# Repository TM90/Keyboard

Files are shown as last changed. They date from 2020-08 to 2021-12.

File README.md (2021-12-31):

# DIY Mechanical Keyboard

## Main Idea:

Have as much as possible open source? Also the tools used to build the keyboard

## Tool usage:
1. KiCAD (schematic, layout) (http://kicad.org/ )
2. avr-gcc (https://gcc.gnu.org/wiki/avr-gcc )
3. Export data for alu body from a layer in the KiCAD layout data

## Electronic
Own layout and schematic but based on this project to keep compatibility with tmk firmware and qmk firmware:

<https://github.com/tmk/HHKB_controller/blob/master/schematic/HHKB_controller_revG.pdf>

### Datasheets

#### Power
- LM1117 3.3V LDO http://cdn-reichelt.de/documents/datenblatt/A200/LM1117-TI.pdf
- NCP1402 step up DCDC Converter https://www.onsemi.com/pub/Collateral/NCP1402-D.PDF ->farnell: out of production
      - Alternative MAX1724 https://www.mouser.de/datasheet/2/256/MAX1722-MAX1724-97057.pdf but no Kicad Lib yet
- MCP 73831/2 Single Cell Lipo Charge Management Controller http://ww1.microchip.com/downloads/en/DeviceDoc/20001984g.pdf

#### Bluetooth
- RN42 Bluetooth Module http://ww1.microchip.com/downloads/en/DeviceDoc/50002328A.pdf

#### Microcontroller
- ATMEGA32U4 8 bit Microcontroller with USB http://ww1.microchip.com/downloads/en/devicedoc/atmel-7766-8-bit-avr-atmega16u4-32u4_datasheet.pdf
- AT90USB1286 8 bit Microcontroller with USB but more IO than ATMEGA32U4  http://ww1.microchip.com/downloads/en/DeviceDoc/doc7593.pdf

## Mechanical
<http://builder.swillkb.com/>

Sandwich case or alu bend case

## Software/Firmware
- <https://qmk.fm/>
- <https://github.com/tmk/tmk_keyboard>

## Other:
<http://www.keyboard-layout-editor.com/#/>

Prototype for Switches without big PCB and description how to build a small keyboard:
<https://learn.sparkfun.com/tutorials/cherry-mx-switch-breakout-hookup-guide>

Fullsize Keyboard matrix example with atmega32u4:
<https://easyeda.com/farmakon/GH80_3000-4f3cee521afd4be3858c4b5cc3b76f9e>

## Manufacturer:
### PCB:
- beta layout <https://de.beta-layout.com/leiterplatten/> 
- LiteOn <https://www.leiton.de/index.html> 
- jlcpcb <https://jlcpcb.com/>
### Mechanical:
Maybe using a front panel service for the keyboard front, aluminum or acrylic would be possible at beta layout

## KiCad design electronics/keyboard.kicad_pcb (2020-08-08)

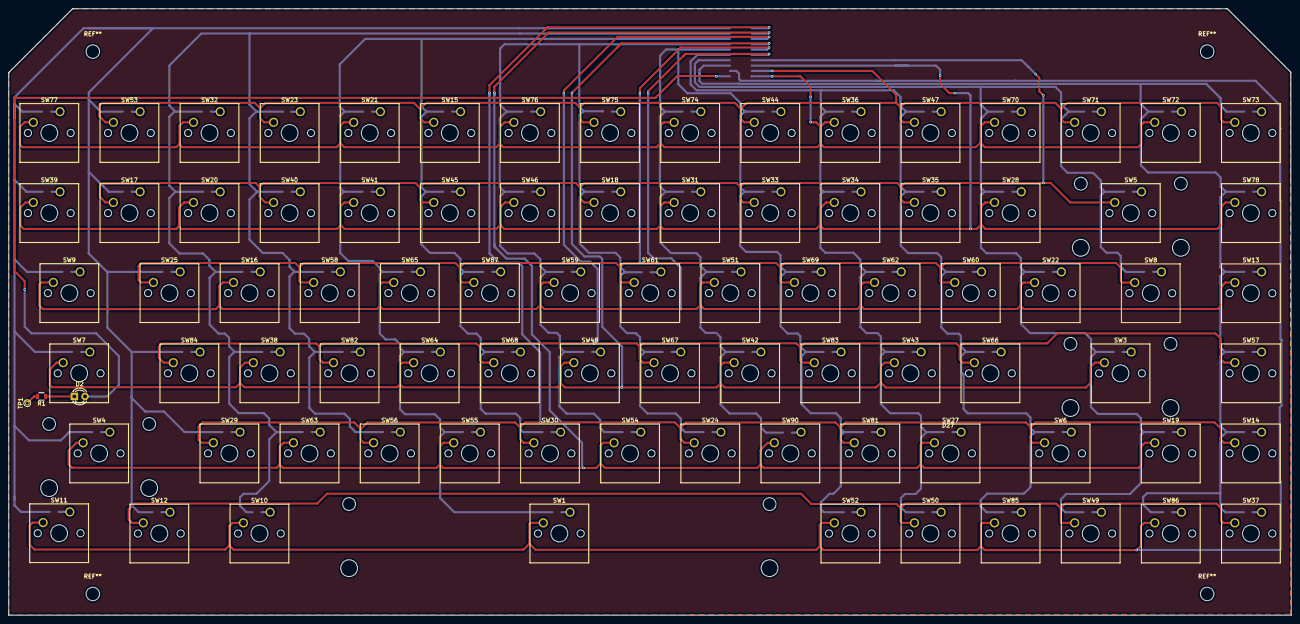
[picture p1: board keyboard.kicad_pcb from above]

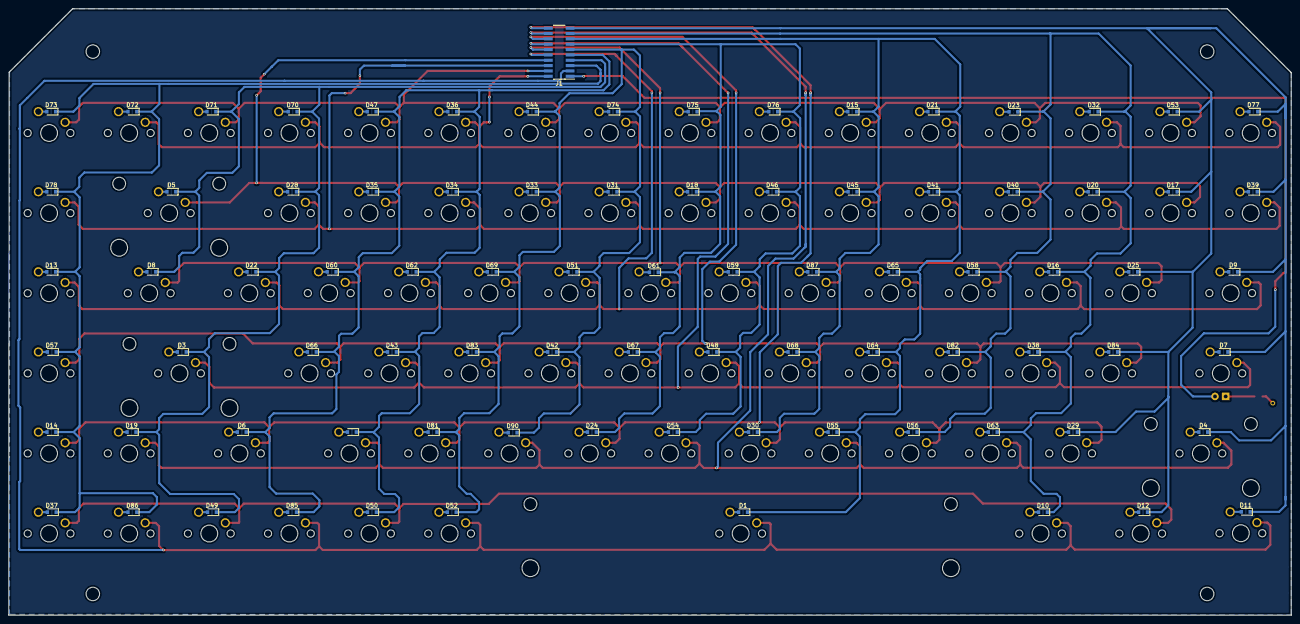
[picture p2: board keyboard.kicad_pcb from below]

Board: 2 copper layers, 305.0 x 144.2 mm, 172 parts (85 on the bottom side), 107 nets.

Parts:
D1, D3, D4, D5, D6, D7, D8, D9, D10, D11, D12, D13, D14, D15, D16, D17, D18, D19, D20, D21, D22, D23, D24, D25, D27, D28, D29, D30, D31, D32, D33, D34, D35, D36, D37, D38, D39, D40, D41, D42, D43, D44, D45, D46, D47, D48, D49, D50, D51, D52, D53, D54, D55, D56, D57, D58, D59, D60, D61, D62, D63, D64, D65, D66, D67, D68, D69, D70, D71, D72, D73, D74, D75, D76, D77, D78, D81, D82, D83, D84, D85, D86, D87, D90: D; D_0805
D2: LED; LED_D3.0mm
J1: CONN_02X10; Pin_Header_Straight_2x10_Pitch1.27mm_SMD
R1: 10k; R_0805
SW1: SW_Push; SW_Cherry_MX1A_6.25u_PCB
SW3, SW4: SW_Push; SW_Cherry_MX1A_2.25u_PCB
SW5: SW_Push; SW_Cherry_MX1A_2.00u_PCB
SW6, SW7: SW_Push; SW_Cherry_MX1A_1.75u_PCB
SW8, SW9: SW_Push; SW_Cherry_MX1A_1.50u_PCB
SW10, SW11, SW12: SW_Push; SW_Cherry_MX1A_1.25u_PCB
SW13, SW14, SW15, SW16, SW17, SW18, SW19, SW20, SW21, SW22, SW23, SW24, SW25, SW27, SW28, SW29, SW30, SW31, SW32, SW33, SW34, SW35, SW36, SW37, SW38, SW39, SW40, SW41, SW42, SW43, SW44, SW45, SW46, SW47, SW48, SW49, SW50, SW51, SW52, SW53, SW54, SW55, SW56, SW57, SW58, SW59, SW60, SW61, SW62, SW63, SW64, SW65, SW66, SW67, SW68, SW69, SW70, SW71, SW72, SW73, SW74, SW75, SW76, SW77, SW78, SW81, SW82, SW83, SW84, SW85, SW86, SW87, SW90: SW_Push; SW_Cherry_MX1A_1.00u_PCB
TP1: TestPoint; PINTST

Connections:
/PA0: D4.1, D7.1, D9.1, D11.1, D12.1, D17.1, D25.1, D29.1, D39.1, D53.1, D77.1, D84.1, J1.19
/PA1: D10.1, D16.1, D20.1, D23.1, D32.1, D38.1, D40.1, D56.1, D58.1, D63.1, D82.1, J1.17
/PA2: D1.1, D15.1, D21.1, D30.1, D41.1, D45.1, D55.1, D64.1, D65.1, D68.1, D87.1, J1.15
/PA3: D18.1, D24.1, D46.1, D48.1, D54.1, D59.1, D61.1, D67.1, D75.1, D76.1, J1.13
/PA4: D31.1, D33.1, D42.1, D44.1, D51.1, D52.1, D69.1, D74.1, D81.1, D83.1, D90.1, J1.11
/PA5: D6.1, D27.1, D34.1, D35.1, D36.1, D43.1, D47.1, D50.1, D60.1, D62.1, D66.1, D85.1, J1.9
/PA6: D3.1, D5.1, D8.1, D19.1, D22.1, D28.1, D49.1, D70.1, D71.1, J1.7
/PA7: D13.1, D14.1, D37.1, D57.1, D72.1, D73.1, D78.1, D86.1, J1.5
/PB0: J1.2, SW21.2, SW32.2, SW36.2, SW70.2, SW72.2, SW74.2, SW76.2, SW77.2
/PB1: J1.4, SW15.2, SW23.2, SW44.2, SW47.2, SW53.2, SW71.2, SW73.2, SW75.2
/PB2: J1.6, SW20.2, SW28.2, SW31.2, SW34.2, SW39.2, SW41.2, SW46.2, SW78.2
/PB3: J1.8, SW5.2, SW17.2, SW18.2, SW33.2, SW35.2, SW40.2, SW45.2
/PB4: J1.10, SW9.2, SW13.2, SW16.2, SW22.2, SW51.2, SW59.2, SW62.2, SW65.2
/PB5: J1.12, SW8.2, SW25.2, SW58.2, SW60.2, SW61.2, SW69.2, SW87.2
/PB6: J1.14, SW3.2, SW7.2, SW38.2, SW42.2, SW43.2, SW48.2, SW64.2
/PB7: J1.16, SW57.2, SW66.2, SW67.2, SW68.2, SW82.2, SW83.2, SW84.2
/PC0: J1.18, SW4.2, SW19.2, SW27.2, SW54.2, SW55.2, SW63.2, SW90.2
/PC1: J1.20, SW6.2, SW14.2, SW24.2, SW29.2, SW30.2, SW56.2, SW81.2
/PC2: J1.3, SW1.2, SW10.2, SW11.2, SW52.2, SW85.2, SW86.2
/SwitchMatrix/COL11: SW12.2, SW37.2, SW49.2, SW50.2
unnamed: D1.2, SW1.1
unnamed: D2.1, R1.1
unnamed: D2.2, J1.1
unnamed: D3.2, SW3.1
unnamed: D4.2, SW4.1
unnamed: D5.2, SW5.1
unnamed: D6.2, SW6.1
unnamed: D7.2, SW7.1
unnamed: D8.2, SW8.1
unnamed: D9.2, SW9.1
unnamed: D10.2, SW10.1
unnamed: D11.2, SW11.1
unnamed: D12.2, SW12.1
unnamed: D13.2, SW13.1
unnamed: D14.2, SW14.1
unnamed: D15.2, SW15.1
unnamed: D16.2, SW16.1
unnamed: D17.2, SW17.1
unnamed: D18.2, SW18.1
unnamed: D19.2, SW19.1
unnamed: D20.2, SW20.1
unnamed: D21.2, SW21.1
unnamed: D22.2, SW22.1
unnamed: D23.2, SW23.1
unnamed: D24.2, SW24.1
unnamed: D25.2, SW25.1
unnamed: D27.2, SW27.1
unnamed: D28.2, SW28.1
unnamed: D29.2, SW29.1
unnamed: D30.2, SW30.1
unnamed: D31.2, SW31.1
unnamed: D32.2, SW32.1
unnamed: D33.2, SW33.1
unnamed: D34.2, SW34.1
unnamed: D35.2, SW35.1
unnamed: D36.2, SW36.1
unnamed: D37.2, SW37.1
unnamed: D38.2, SW38.1
unnamed: D39.2, SW39.1
unnamed: D40.2, SW40.1
unnamed: D41.2, SW41.1
unnamed: D42.2, SW42.1
unnamed: D43.2, SW43.1
unnamed: D44.2, SW44.1
unnamed: D45.2, SW45.1
unnamed: D46.2, SW46.1
unnamed: D47.2, SW47.1
unnamed: D48.2, SW48.1
unnamed: D49.2, SW49.1
unnamed: D50.2, SW50.1
unnamed: D51.2, SW51.1
unnamed: D52.2, SW52.1
unnamed: D53.2, SW53.1
unnamed: D54.2, SW54.1
unnamed: D55.2, SW55.1
unnamed: D56.2, SW56.1
unnamed: D57.2, SW57.1
unnamed: D58.2, SW58.1
unnamed: D59.2, SW59.1
unnamed: D60.2, SW60.1
unnamed: D61.2, SW61.1
unnamed: D62.2, SW62.1
unnamed: D63.2, SW63.1
unnamed: D64.2, SW64.1
unnamed: D65.2, SW65.1
unnamed: D66.2, SW66.1
unnamed: D67.2, SW67.1
unnamed: D68.2, SW68.1
unnamed: D69.2, SW69.1
unnamed: D70.2, SW70.1
unnamed: D71.2, SW71.1
unnamed: D72.2, SW72.1
unnamed: D73.2, SW73.1
unnamed: D74.2, SW74.1
unnamed: D75.2, SW75.1
unnamed: D76.2, SW76.1
unnamed: D77.2, SW77.1
unnamed: D78.2, SW78.1
unnamed: D81.2, SW81.1
unnamed: D82.2, SW82.1
unnamed: D83.2, SW83.1
unnamed: D84.2, SW84.1
unnamed: D85.2, SW85.1
unnamed: D86.2, SW86.1
unnamed: D87.2, SW87.1
unnamed: D90.2, SW90.1
unnamed: R1.2, TP1.1

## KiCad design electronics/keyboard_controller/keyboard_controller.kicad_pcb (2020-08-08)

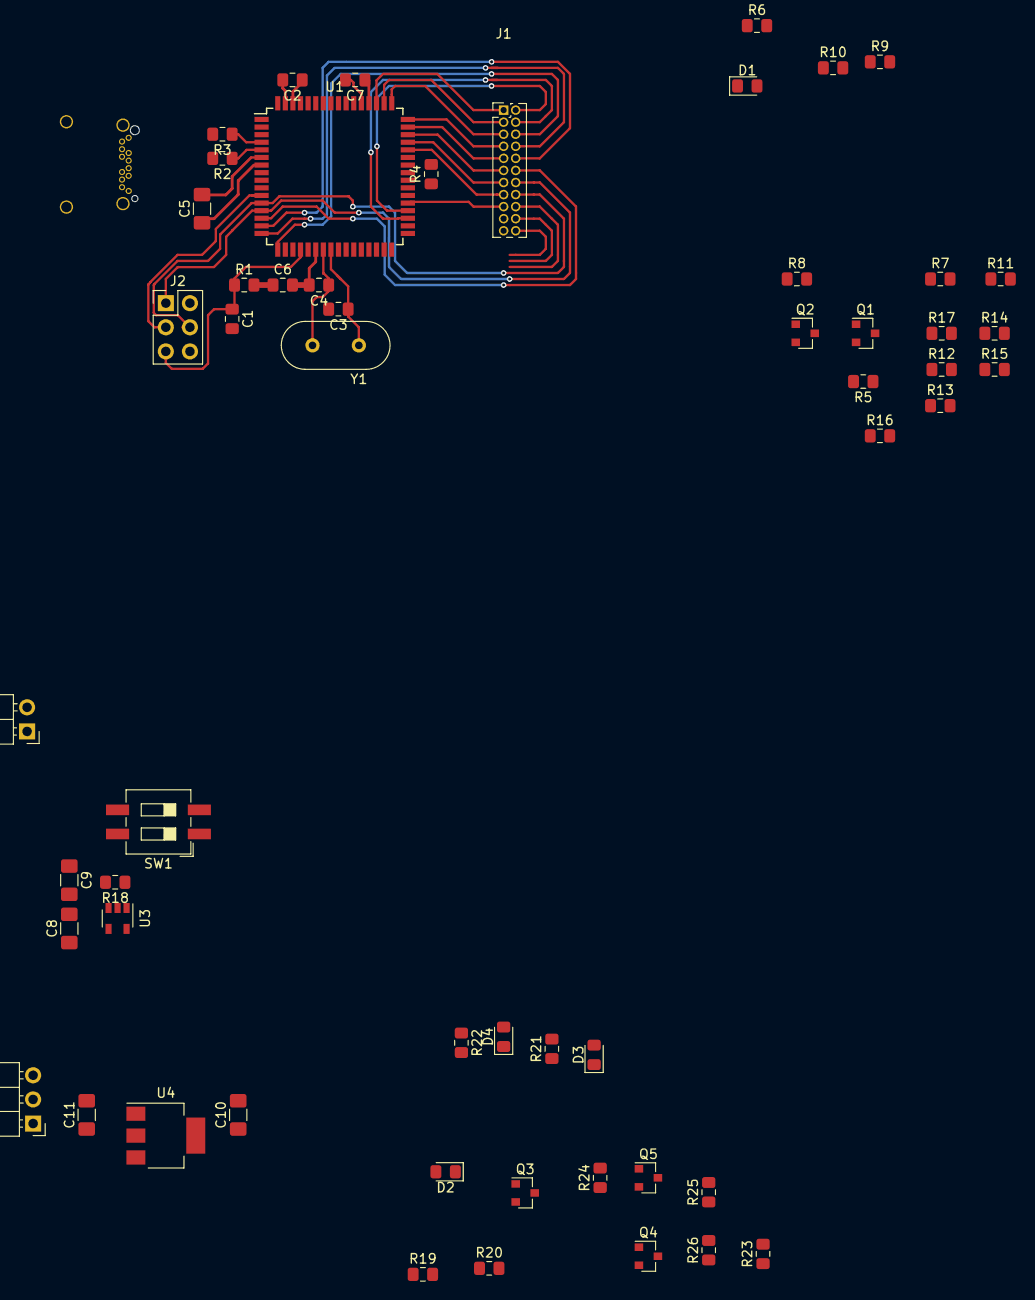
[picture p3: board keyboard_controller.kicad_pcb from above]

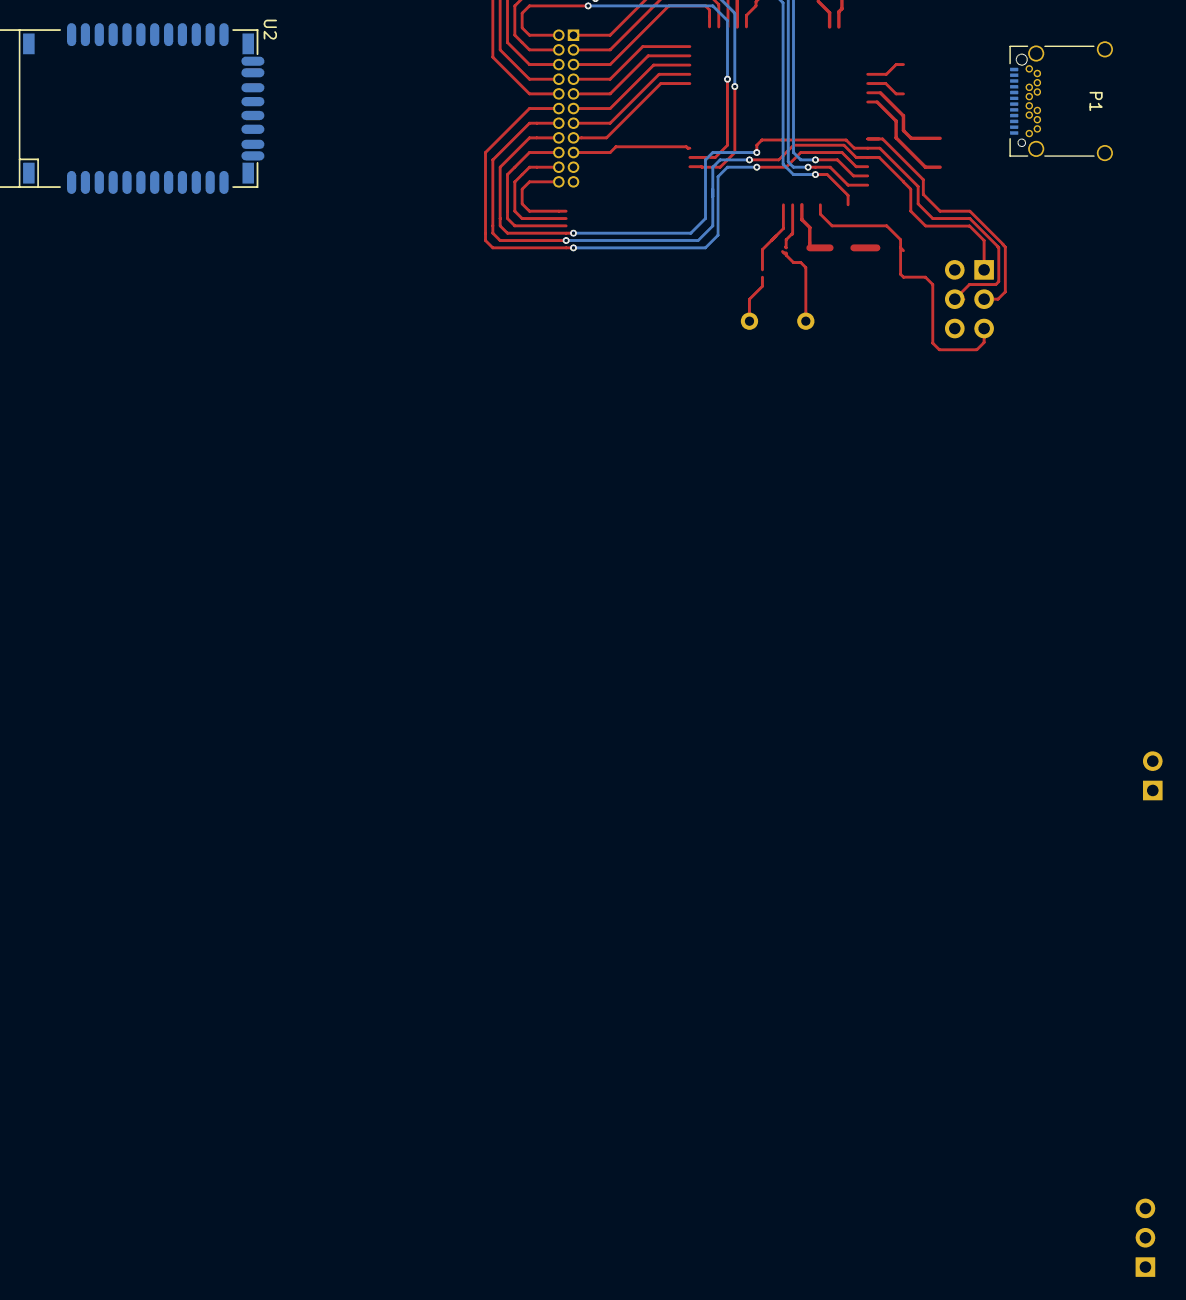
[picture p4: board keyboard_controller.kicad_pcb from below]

Board: 2 copper layers, 57 parts (2 on the bottom side), 62 nets.

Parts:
C1, C2, C6, C7: 100n; C_0805_2012Metric_Pad1.15x1.40mm_HandSolder
C3, C4: 22p; C_0805_2012Metric_Pad1.15x1.40mm_HandSolder
C5: 1u; C_1206_3216Metric_Pad1.42x1.75mm_HandSolder
C8, C9: 4u7; C_1206_3216Metric_Pad1.42x1.75mm_HandSolder
C10, C11: 10u; C_1206_3216Metric_Pad1.42x1.75mm_HandSolder
D1, D3, D4: LED; LED_0805_2012Metric_Pad1.15x1.40mm_HandSolder
D2: D_Schottky; D_0805_2012Metric_Pad1.15x1.40mm_HandSolder
J1: Conn_02x11_Odd_Even; PinHeader_2x11_P1.27mm_Vertical
J2: AVR-ISP-6; PinHeader_2x03_P2.54mm_Vertical
J3: Conn_01x02_Male; PinHeader_1x02_P2.54mm_Horizontal
J4: Conn_01x03_Male; PinHeader_1x03_P2.54mm_Horizontal
P1: USB_C_Plug_USB2.0; USB_C_Receptacle_Amphenol_12401548E4-2A_CircularHoles
Q1, Q2, Q4: Q_NMOS_DGS; SOT-23
Q3, Q5: Q_PMOS_DGS; SOT-23
R1, R4, R6, R19, R21, R22: 1k; R_0805_2012Metric_Pad1.15x1.40mm_HandSolder
R2, R3: 22; R_0805_2012Metric_Pad1.15x1.40mm_HandSolder
R5, R7, R8, R10, R11, R12, R14, R16, R20, R23, R24, R25, R26: 10k; R_0805_2012Metric_Pad1.15x1.40mm_HandSolder
R9: 0; R_0805_2012Metric_Pad1.15x1.40mm_HandSolder
R13, R15, R17: 15k; R_0805_2012Metric_Pad1.15x1.40mm_HandSolder
R18: PROG; R_0805_2012Metric_Pad1.15x1.40mm_HandSolder
SW1: SW_DPST; SW_DIP_SPSTx02_Slide_6.7x6.64mm_W8.61mm_P2.54mm_LowProfile
U1: AT90USB1286-AU; TQFP-64_14x14mm_P0.8mm
U2: RN42
U3: MCP73832-3-OT; SOT-23-5
U4: LM1117-3.3; SOT-223-3_TabPin2
Y1: 16MHz; Crystal_HC49-4H_Vertical

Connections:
+3V3: Q1.2, Q2.2, R5.2, R6.2, R8.2, R10.1, SW1.2, U2.11
+5V: C6.1, C7.1, C10.1, J2.2, J4.1, R1.2, R7.1, R11.1, U1.21, U1.52, U1.64, U4.3
/AREF: C2.1, U1.62
/CONN: R12.1, R13.2, U2.3
/DMINUS: P1.A7, R3.2
/DPLUS: P1.A6, R2.2
/FACTORY_RESET: R9.2, U2.22
/LED_STS: D1.1, U2.21
/LINKED: U1.55, U2.19
/MCU_RX: Q1.1, R7.2, U1.27
/MCU_TX: R14.2, U1.28
/PA0: J1.1, U1.51
/PA1: J1.3, U1.50
/PA2: J1.5, U1.49
/PA3: J1.7, U1.48
/PA4: J1.9, U1.47
/PA5: J1.11, U1.46
/PA6: J1.13, U1.45
/PA7: J1.15, U1.44
/PB0: J1.20, U1.10
/PB1: J1.18, J2.3, U1.11
/PB2: J1.16, J2.4, U1.12
/PB3: J1.14, J2.1, U1.13
/PB4: J1.12, U1.14
/PB5: J1.10, U1.15
/PB6: J1.8, U1.16
/PB7: J1.6, U1.17
/PC0: J1.4, U1.35
/PC1: J1.2, U1.36
/PC2: J1.17, U1.37
/PC3: J1.22, U1.38
/PD5: R16.2, U1.30
/PF0: R25.1, R26.2, U1.61
/PF1: Q2.1, R11.2, U1.60
/PF4: Q4.2, R23.2, U1.57
/PF7: R12.2, U1.54
/RESET: C1.1, J2.5, R1.1, U1.20
/RN42_CTS: R16.1, R17.2, U2.16
/RN42_RTS: Q2.3, R8.1, U2.15
/RN42_RX: R14.1, R15.2, U2.13
/RN42_TX: Q1.3, R5.1, U2.14
/Sheet5D061573/Chrg: D4.1, U3.1
/Sheet5D061573/LIPO_RAW: C9.1, J3.1, Q5.1, R24.2, SW1.3, U3.3
/Sheet5D061573/LIPO_SW: Q3.3, SW1.4
/Sheet5D061573/PSEL: D2.1, J4.3, Q3.1, R22.2
/Sheet5D061573/Vout33_int: C11.1, SW1.1, U4.2
/VUSB: C8.1, D2.2, P1.A4, P1.A9, P1.B4, P1.B9, R19.2, R21.2, U1.3, U1.8, U3.4
GND: C1.2, C2.2, C3.2, C4.2, C5.2, C6.2, C7.2, C8.2, C9.2, C10.2, C11.2, D3.1, J1.21, J2.6, J3.2, J4.2, P1.A1, P1.A12, P1.B1, P1.B12, P1.S1, Q4.3, R4.1, R13.1, R15.1, R17.1, R18.2, R20.1, R23.1, R26.1, U1.6, U1.22, U1.53, U1.63, U2.1, U2.12, U2.28, U2.29, U2.36, U3.2, U4.1
unnamed: C3.1, U1.24, Y1.1
unnamed: C4.1, U1.23, Y1.2
unnamed: C5.1, U1.7
unnamed: D1.2, R6.1
unnamed: D3.2, R21.1
unnamed: D4.2, R22.1
unnamed: Q3.2, R19.1, R20.2
unnamed: Q4.1, Q5.2, R24.1
unnamed: Q5.3, R25.2
unnamed: R2.1, U1.5
unnamed: R3.1, U1.4
unnamed: R4.2, U1.43
unnamed: R9.1, R10.2
unnamed: R18.1, U3.5

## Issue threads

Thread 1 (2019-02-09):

Add GND pin to pinheader for next version

TM90, 2019-02-09:
At the current version in the test pcb the GND Pin for the shif key LED is added as test pin and not on the pin header.

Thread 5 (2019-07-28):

COL11 not connected

TM90, 2019-07-28:
Extend the connector in the keyboard schematic...
Workaround at the moment Connect COL11 with a connector from SW12 to the led which leads to the connector

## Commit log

2018-07-02 Added link for Cherry MX switch breakout board.
2018-07-06 Added initial Schematic
    - Todo
    - Add Bluetooth Module
    - Add Lipo Power Supply
    - connect switch matrix
    [SwitchMatrix.sch, keyboard.kicad_pcb, keyboard.sch]
2018-07-06 Updated .gitignore to ignore kicad backups and other temp files
2018-07-06 Added some structure to the schematics`
    [Interfaces.sch, Supply.sch, SwitchMatrix.sch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]
2018-07-07 Updated Structure
    - ISP programmer is now on interface sheet
    - added en and decoder to SwitchMatrix sheet
    [Interfaces.sch, SwitchMatrix.sch, keyboard.sch]
2018-07-07 Added Reset circuit and decap for en and decoders
    [Supply.sch, SwitchMatrix.sch, keyboard.sch]
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2018-07-21 Added additional Supply for remote usage.
    Started working on Bluetooth `
    [Interfaces.sch, Supply.sch, SwitchMatrix.sch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]
2018-07-21 Added Bluetoothmodule
    Now only the switch matrix is missing
    [Interfaces.sch, keyboard.sch]
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2018-08-10 Changed Controller to AT90USB now the additional circuitry at the matrix can be removed
    [Interfaces.sch, Supply.sch, SwitchMatrix.sch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]
2018-08-10 removed en and decoder from matrix now the controls are direct
    [SwitchMatrix.sch, keyboard.sch]
2018-08-10 Finished the matrix
    Now the schematic should be at an initial finished point
    [SwitchMatrix.sch, keyboard.sch]
2018-08-11 Annotated the schematics...
    Did a first ERC run looked fine...
    [Interfaces.sch, Supply.sch, SwitchMatrix.sch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]
2018-08-11 create an initial netlist and started assigning the footprints
    [Interfaces.sch, Supply.sch, SwitchMatrix.sch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]
2018-08-25 Started placement step
    [keyboard.kicad_pcb]
2018-08-25 Seperated the Buttons from the rest
    [keyboard.kicad_pcb]
2018-08-25 Seperated diodes
    [keyboard.kicad_pcb]
2018-08-25 seperated elements for the controller
    [keyboard.kicad_pcb]
2018-08-25 Clustured Suplly Circuitry
    [keyboard.kicad_pcb]
2018-08-27 Seperated elements in a sane way...
    [Interfaces.sch, Supply.sch, SwitchMatrix.sch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]
2018-08-29 Updated the usb connector to micro usb at the momement because it is in the lib
    [Interfaces.sch, keyboard.kicad_pcb]
2018-08-29 Started working on the switches placements
    [keyboard.kicad_pcb]
2018-09-16 Worked on Placement changed the mothod to do it...
    [keyboard.kicad_pcb]
2018-09-16 Placement progress now only 1u elements left for placment of the switch matrix
    [keyboard.kicad_pcb]
2018-09-16 Initial Placement for the switches
    [keyboard.kicad_pcb]
2018-09-22 Placed Diodes and Main controller
    [keyboard.kicad_pcb]
2018-09-22 Added dimension as indecator
    [keyboard.kicad_pcb]
2018-10-10 Changed keyboard schematic since now keyboard and controller will be seperated
    [Interfaces.sch, Supply.sch, SwitchMatrix.sch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]
2018-10-12 Placed everthing again :(
    [keyboard.kicad_pcb]
2018-10-12 Started routing for this the schematic also gets restructured
    [keyboard.kicad_pcb]
2018-10-12 routed another row
    [SwitchMatrix.sch, keyboard.kicad_pcb]
2018-10-12 routed the 2nd column
    [SwitchMatrix.sch, keyboard.kicad_pcb]
2018-10-13 Added two columns
    [SwitchMatrix.sch, keyboard.kicad_pcb]
2018-10-13 Worked further on the layout
    [SwitchMatrix.sch, keyboard.kicad_pcb]
2018-10-13 more layout
    [SwitchMatrix.sch, keyboard.kicad_pcb]
2018-10-21 worked further on interconnect
    [SwitchMatrix.sch, keyboard.kicad_pcb]
2018-10-21 Further work on interconnect
    [SwitchMatrix.sch, keyboard.kicad_pcb]
2018-10-21 Another ROW layouted
    [SwitchMatrix.sch, keyboard.kicad_pcb]
2018-10-21 Finished Row layout
    Todo:
    - Route the last columns
    - change some layers in the layout (diodes, connector)
    - add fill
    [SwitchMatrix.sch, keyboard.kicad_pcb]
2018-10-22 routed two columns
    [SwitchMatrix.sch, keyboard.kicad_pcb]
2018-10-22 Added another column 3 left
    [SwitchMatrix.sch, keyboard.kicad_pcb]
2018-10-24 Added another column 2 to go
    [SwitchMatrix.sch, keyboard.kicad_pcb]
2018-10-25 Signal Routing done!
    - Area Fill
    - change the layers of rows and columns to swap the diodes away from
    the top
    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
    [SwitchMatrix.sch, keyboard.kicad_pcb]
2018-10-30 Device Cleanup:
    - Fill areas
    - change layers of diodes
    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
    [SwitchMatrix.sch, keyboard.kicad_pcb]
2018-10-30 Changed layers for the routes now diodes have to be moved to the other side
    [keyboard.kicad_pcb]
2018-10-30 Updated connector placed the diodes on the right side.
    - Area fill
    - some routing to the connector
    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
    [keyboard.kicad_pcb, keyboard.sch]
2018-10-31 Corrected some footprints worked on connector routing 4 pins to go...
    [keyboard.kicad_pcb]
2018-10-31 Initial complete signal routing of the connector
    [keyboard.kicad_pcb]
2019-01-05 Fixed strange drc errors with replacing vias
    [keyboard.kicad_pcb]
2019-01-06 Added outline and some drill holes
    todo:
    - Additional 2 drill holes
    - update fill zones
    - add led for shift switch
    [keyboard.kicad_pcb]
2019-01-06 updated pcb
    [keyboard.kicad_pcb]
2019-01-06 Update keyboard.kicad_pcb
    Updated Via size
    Fixed fill area size
    - 2 additional drill holes
    - led for shift
    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
    [keyboard.kicad_pcb]
2019-01-07 kicad5 fix and shift led in schematic
    - Fixed schematic for kicad5
    - added shift led in schematic
    Todo
    - Layout the led
    [SwitchMatrix-2019-01-07-23-27-31.sch, SwitchMatrix-2019-01-07-23-29-17.sch, keyboard-2019-01-07-23-27-31.sch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]
2019-01-08 Updated PCB
    Initial finished version
    [keyboard.kicad_pcb]
2019-01-08 Added PCB outline in edge cut layer
    [keyboard.kicad_pcb]
2019-07-28 Added initial keyboard controller schematic
    [keyboard_controller.kicad_pcb, keyboard_controller.sch, keyboard_controller_power.sch]
2019-07-28 Fixed some minor issues in the keyboard controller schematics
    Started placement for the layout
    [keyboard.kicad_pcb, keyboard_controller.sch, keyboard_controller_power.sch]
2019-12-08 Worked on Placement
    [keyboard_controller.kicad_pcb, keyboard_controller.sch, keyboard_controller_power.sch]
2020-08-08 Worked no keyboard controller layout
    [SwitchMatrix.sch, keyboard.kicad_pcb, keyboard.sch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]
2021-11-08 Update README.md
    https://forum.kicad.info/t/warning-avoid-all-links-to-kicad-pcb-org-use-kicad-org/31521
